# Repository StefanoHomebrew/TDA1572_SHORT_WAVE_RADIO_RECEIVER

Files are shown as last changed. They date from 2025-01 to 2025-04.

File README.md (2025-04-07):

Quello che vedete è molto sperimentale, in fase di sviluppo. Non posso dare assistenza tecnica e file gerber... Se trovate BUG e avete consigli utili, scrivetemi! Grazie!  Altrimenti che divertimento è!... A very experimental shortwave radio receiver with TDA1572, a vintage integrated circuit, external PLL & DDS Vfo and Arduino Mega 256. Gennaio 2025, AM-SSB-RTTY(in fase di sviluppo)---Aprile 2025--- Nuova release con AGC NUOVO! : RX_TDA1572_AGC_NEW_REV2.kicad_pcb

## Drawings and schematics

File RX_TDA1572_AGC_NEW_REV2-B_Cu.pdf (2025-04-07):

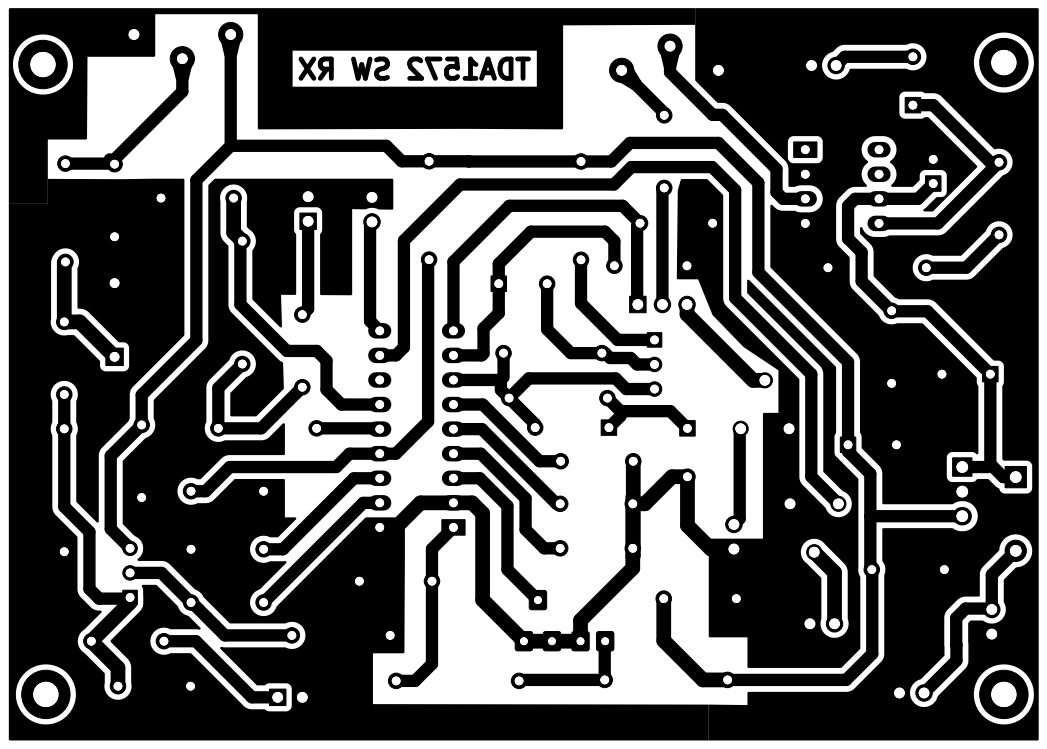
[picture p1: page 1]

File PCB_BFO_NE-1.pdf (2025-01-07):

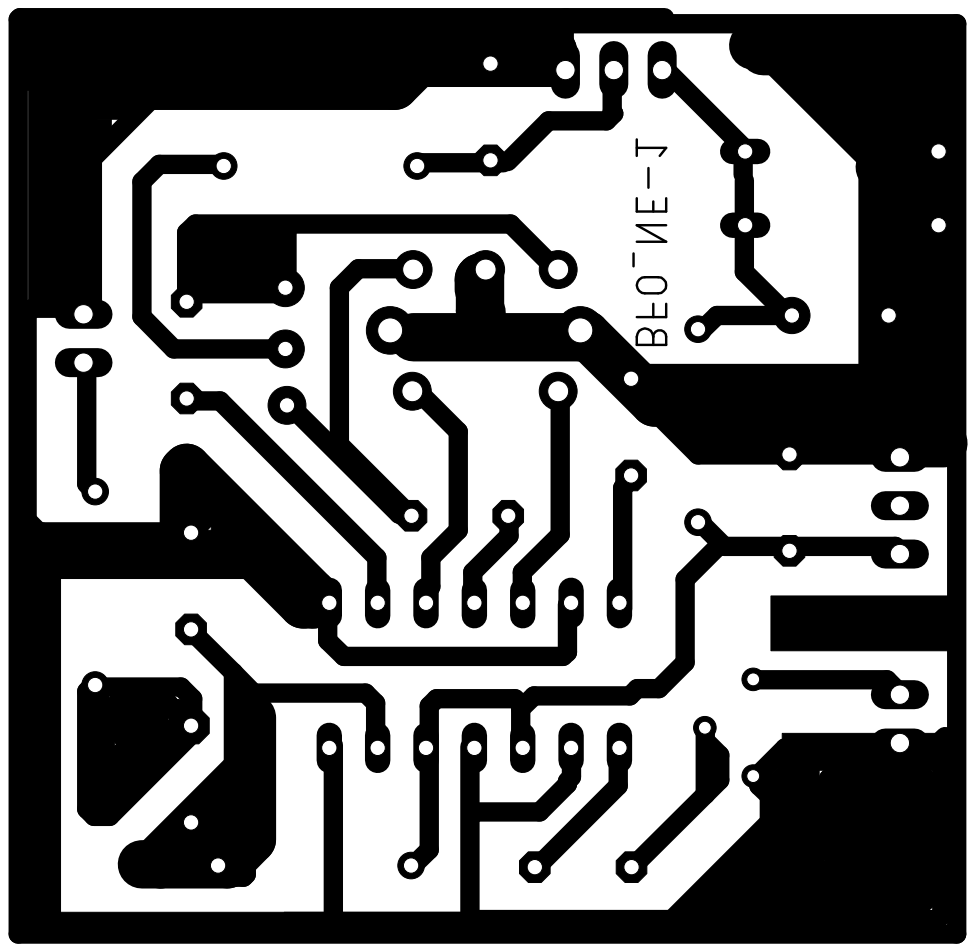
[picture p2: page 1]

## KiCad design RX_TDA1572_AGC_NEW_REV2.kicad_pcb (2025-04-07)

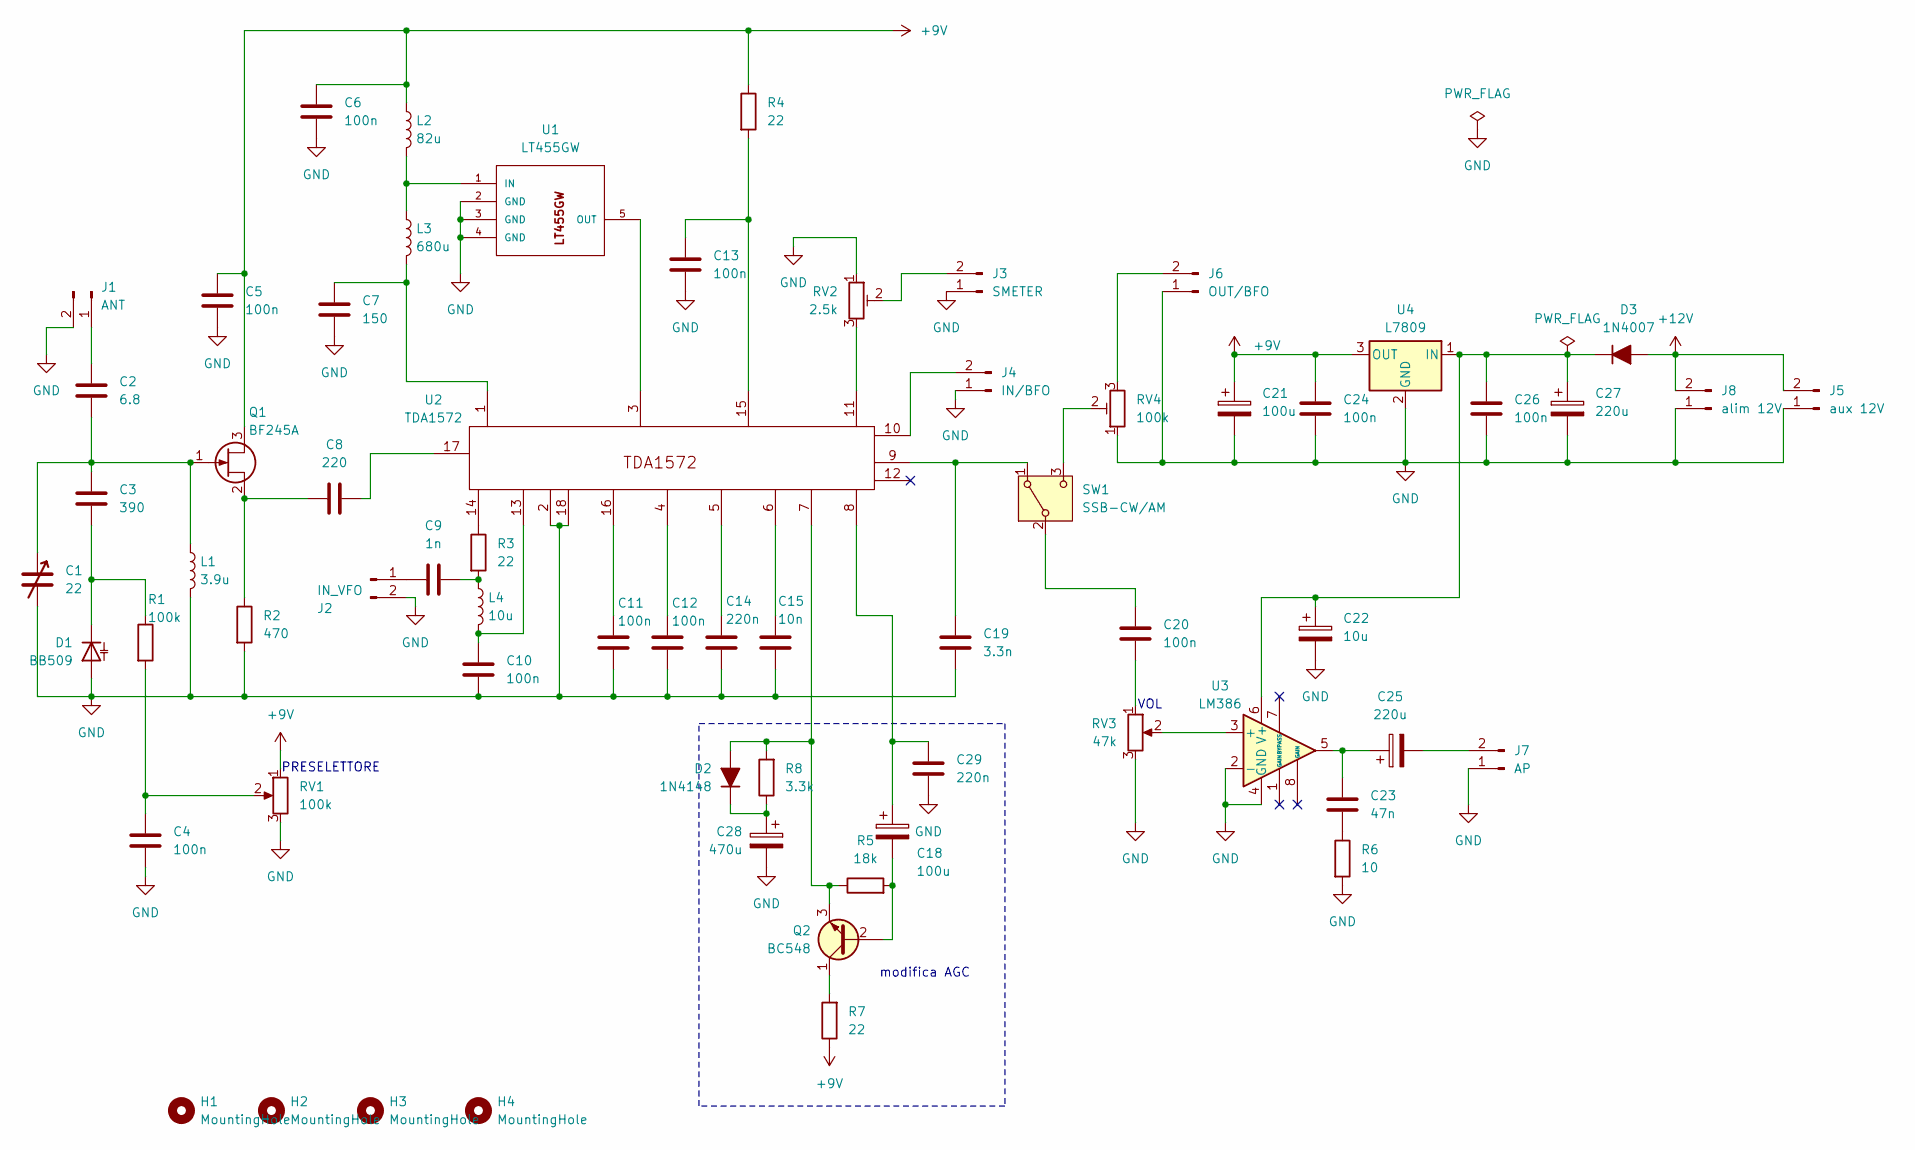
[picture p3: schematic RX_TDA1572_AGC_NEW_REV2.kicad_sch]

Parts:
C1: 22; C_Rect_L9.0mm_W3.4mm_P7.50mm_MKT
C2: 6.8; C_Rect_L9.0mm_W3.4mm_P7.50mm_MKT
C3: 390; C_Rect_L9.0mm_W3.4mm_P7.50mm_MKT
C4, C5, C6, C10, C11, C12, C13, C20, C24, C26: 100n; C_Rect_L9.0mm_W3.4mm_P7.50mm_MKT
C7: 150; C_Rect_L9.0mm_W3.4mm_P7.50mm_MKT
C8: 220; C_Rect_L9.0mm_W3.4mm_P7.50mm_MKT
C9: 1n; C_Rect_L9.0mm_W3.4mm_P7.50mm_MKT
C14, C29: 220n; C_Rect_L9.0mm_W3.4mm_P7.50mm_MKT
C15: 10n; C_Rect_L9.0mm_W3.4mm_P7.50mm_MKT
C18, C21: 100u; CP_Radial_D8.0mm_P5.00mm
C19: 3.3n; C_Rect_L9.0mm_W3.4mm_P7.50mm_MKT
C22: 10u; CP_Radial_D5.0mm_P2.50mm
C23: 47n; C_Rect_L9.0mm_W3.4mm_P7.50mm_MKT
C25, C27: 220u; CP_Radial_D8.0mm_P5.00mm
C28: 470u; CP_Radial_D8.0mm_P5.00mm
D1: BB509; D_A-405_P7.62mm_Horizontal
D2: 1N4148; D_DO-35_SOD27_P7.62mm_Horizontal
D3: 1N4007; D_DO-41_SOD81_P7.62mm_Horizontal
H1, H2, H3, H4: MountingHole; MountingHole_2.5mm_Pad
J1: ANT; PinHeader_1x02_P2.54mm_Vertical
J2: IN_VFO; PinHeader_1x02_P2.54mm_Vertical
J3: SMETER; PinHeader_1x02_P2.54mm_Vertical
J4: IN/BFO; PinHeader_1x02_P2.54mm_Vertical
J5: aux 12V; PinHeader_1x02_P2.54mm_Vertical
J6: OUT/BFO; PinHeader_1x02_P2.54mm_Vertical
J7: AP; PinHeader_1x02_P2.54mm_Vertical
J8: alim 12V; PinHeader_1x02_P2.54mm_Vertical
L1: 3.9u; L_Axial_L7.0mm_D3.3mm_P12.70mm_Horizontal_Fastron_MICC
L2: 82u; L_Axial_L7.0mm_D3.3mm_P12.70mm_Horizontal_Fastron_MICC
L3: 680u; L_Axial_L7.0mm_D3.3mm_P12.70mm_Horizontal_Fastron_MICC
L4: 10u; L_Axial_L7.0mm_D3.3mm_P12.70mm_Horizontal_Fastron_MICC
Q1: BF245A; TO-92_Inline_Wide
Q2: BC548; TO-92_Inline_Wide_CBE
R1: 100k; R_Axial_DIN0207_L6.3mm_D2.5mm_P10.16mm_Horizontal
R2: 470; R_Axial_DIN0207_L6.3mm_D2.5mm_P10.16mm_Horizontal
R3, R4, R7: 22; R_Axial_DIN0207_L6.3mm_D2.5mm_P10.16mm_Horizontal
R5: 18k; R_Axial_DIN0207_L6.3mm_D2.5mm_P10.16mm_Horizontal
R6: 10; R_Axial_DIN0207_L6.3mm_D2.5mm_P10.16mm_Horizontal
R8: 3.3k; R_Axial_DIN0207_L6.3mm_D2.5mm_P10.16mm_Horizontal
RV1: 100k; Potentiometer_Piher_PT-15-H01_Horizontal
RV2: 2.5k; Potentiometer_Runtron_RM-065_Vertical
RV3: 47k; Potentiometer_Piher_PT-15-H01_Horizontal
RV4: 100k; Potentiometer_Runtron_RM-065_Vertical
SW1: SSB-CW/AM; PinHeader_1x03_P2.54mm_Vertical
U1: LT455GW; CFW455IT
U2: TDA1572; DIP-18_W7.62mm_Socket_LongPads
U3: LM386; DIP-8_W7.62mm_Socket_LongPads
U4: L7809; TO-220-3_Vertical

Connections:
+9V: C5.1, C6.1, C21.1, C24.1, L2.1, Q1.3 (D), R4.1, R7.1, RV1.1, U4.3 (OUT)
+12V: D3.2 (A), J5.2, J8.2
GND: C1.2, C4.2, C5.2, C6.2, C7.2, C10.1, C11.1, C12.1, C13.2, C14.1, C15.1, C19.2, C21.2, C22.2, C24.2, C26.2, C27.2, C28.2, C29.2, D1.2 (A), J1.2, J2.2, J3.1, J4.1, J5.1, J6.1, J7.1, J8.1, L1.2, R2.2, R6.2, RV1.3, RV2.1, RV3.3, RV4.1, U1.2 (GND), U1.3 (GND), U1.4 (GND), U2.2, U2.18, U3.2 (-), U3.4 (GND), U4.2 (GND)
unnamed: C4.1, R1.2, RV1.2
unnamed: C7.1, L3.2, U2.1
unnamed: C8.2, U2.17
unnamed: C9.2, L4.1, R3.2
unnamed: C10.2, L4.2, U2.13
unnamed: C11.2, U2.16
unnamed: C12.2, U2.4
unnamed: C13.1, R4.2, U2.15
unnamed: C14.2, U2.5
unnamed: C15.2, U2.6
unnamed: C18.1, C29.1, U2.8
unnamed: C20.1, RV3.1
unnamed: C23.1, C25.1, U3.5
unnamed: C23.2, R6.1
unnamed: C3.2, D1.1 (K), R1.1
unnamed: D2.2 (A), Q2.3 (E), R5.1, R8.2, U2.7
unnamed: C28.1, D2.1 (K), R8.1
unnamed: C22.1, C26.1, C27.1, D3.1 (K), U3.6 (V+), U4.1 (IN)
unnamed: C2.1, J1.1
unnamed: C9.1, J2.1
unnamed: J3.2, RV2.2
unnamed: J4.2, U2.10
unnamed: J6.2, RV4.3
unnamed: C25.2, J7.2
unnamed: C1.1, C2.2, C3.1, L1.1, Q1.1 (G)
unnamed: C8.1, Q1.2 (S), R2.1
unnamed: C18.2, Q2.2 (B), R5.2
unnamed: Q2.1 (C), R7.2
unnamed: R3.1, U2.14
unnamed: RV2.3, U2.11
unnamed: C19.1, SW1.1 (A), U2.9
unnamed: C20.2, SW1.2 (B)
unnamed: RV4.2, SW1.3 (C)
unnamed: L2.2, L3.1, U1.1 (IN)
unnamed: U1.5 (OUT), U2.3
unnamed: RV3.2, U3.3 (+)

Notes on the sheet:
modifica AGC
PRESELETTORE
VOL

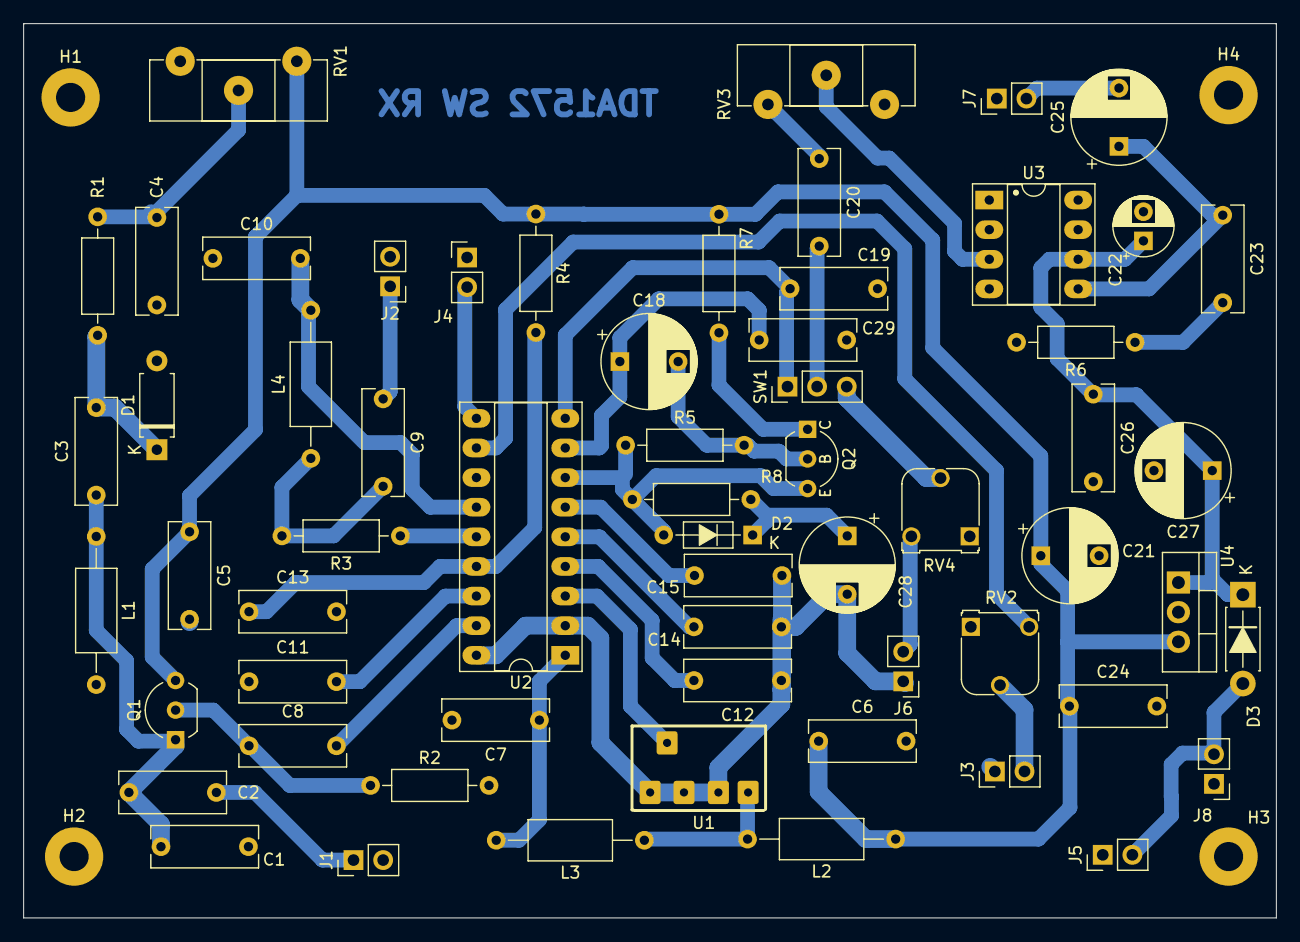
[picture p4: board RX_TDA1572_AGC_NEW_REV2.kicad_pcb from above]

Board: 2 copper layers, 107.4 x 76.7 mm, 65 parts (0 on the bottom side), 39 nets.

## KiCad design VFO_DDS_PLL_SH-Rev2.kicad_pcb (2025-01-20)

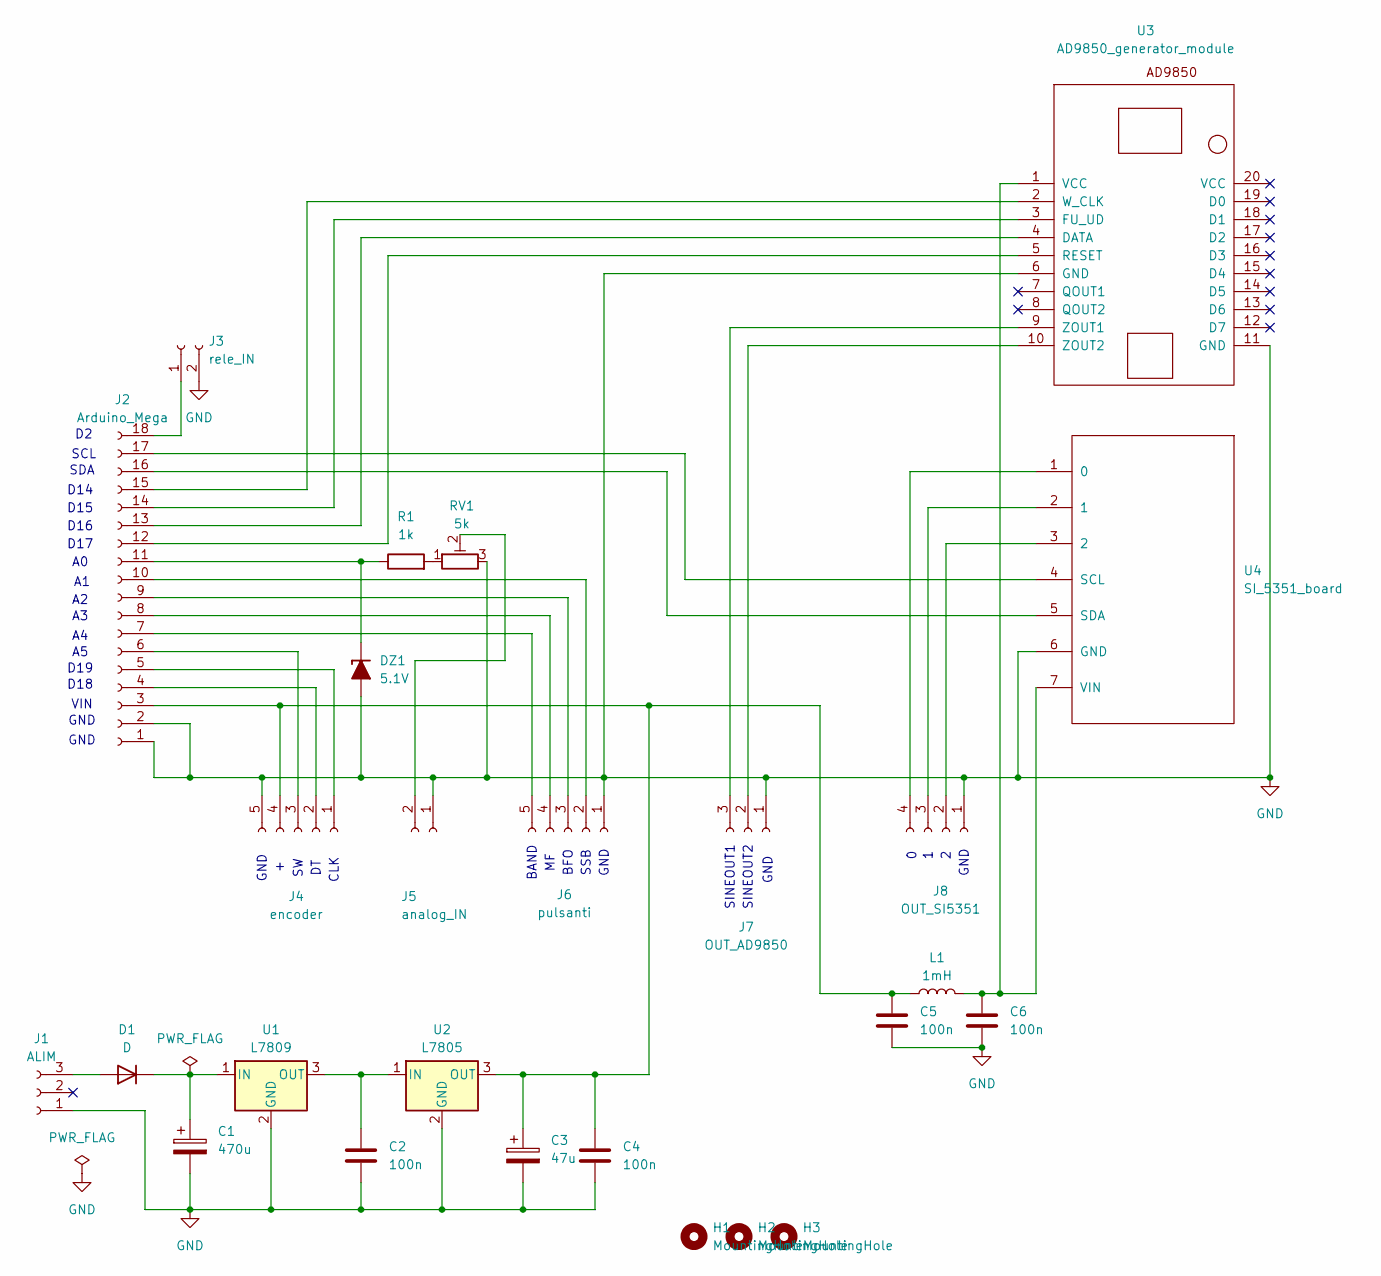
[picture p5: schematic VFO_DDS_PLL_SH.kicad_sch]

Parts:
C1: 470u; CP_Radial_D8.0mm_P3.50mm
C2, C4, C5, C6: 100n; C_Disc_D4.3mm_W1.9mm_P5.00mm
C3: 47u; CP_Radial_D8.0mm_P3.50mm
D1: D; D_DO-41_SOD81_P12.70mm_Horizontal
DZ1: 5.1V; D_DO-34_SOD68_P7.62mm_Horizontal_Zener
H1, H2, H3: MountingHole; MountingHole_2.2mm_M2_Pad
J1: ALIM; PinHeader_1x03_P2.54mm_Vertical
J2: Arduino_Mega; PinHeader_1x18_P2.54mm_Vertical
J3: rele_IN; PinHeader_1x02_P2.54mm_Vertical
J4: encoder; PinHeader_1x05_P2.54mm_Vertical
J5: analog_IN; PinHeader_1x02_P2.54mm_Vertical
J6: pulsanti; PinHeader_1x05_P2.54mm_Vertical
J7: OUT_AD9850; PinHeader_1x03_P2.54mm_Vertical
J8: OUT_SI5351; PinHeader_1x04_P2.54mm_Vertical
L1: 1mH; L_Axial_L5.3mm_D2.2mm_P10.16mm_Horizontal_Vishay_IM-1
R1: 1k; R_Axial_DIN0207_L6.3mm_D2.5mm_P10.16mm_Horizontal
RV1: 5k; Potentiometer_Runtron_RM-065_Vertical
U1: L7809; TO-220-3_Horizontal_TabDown
U2: L7805; TO-220-3_Horizontal_TabDown
U3: AD9850_generator_module; AD9850-MODUL
U4: SI_5351_board; SI5351_MODULE

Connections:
GND: C1.2, C2.2, C3.2, C4.2, C5.2, C6.2, DZ1.2 (A), J1.1, J2.1, J2.2, J3.2, J4.5, J5.1, J6.1, J7.1, J8.1, RV1.3, U1.2 (GND), U2.2 (GND), U3.6 (GND), U3.11 (GND), U4.6 (GND)
unnamed: D1.2 (A), J1.3
unnamed: C1.1, D1.1 (K), U1.1 (IN)
unnamed: DZ1.1 (K), J2.11, R1.1
unnamed: C3.1, C4.1, C5.1, J2.3, J4.4, L1.1, U2.3 (OUT)
unnamed: J2.4, J4.2
unnamed: J2.5, J4.1
unnamed: J2.6, J4.3
unnamed: J2.7, J6.5
unnamed: J2.8, J6.4
unnamed: J2.9, J6.3
unnamed: J2.10, J6.2
unnamed: J2.12, U3.5 (RESET)
unnamed: J2.13, U3.4 (DATA)
unnamed: J2.14, U3.3 (FU_UD)
unnamed: J2.15, U3.2 (W_CLK)
unnamed: J2.16, U4.5 (SDA)
unnamed: J2.17, U4.4 (SCL)
unnamed: J2.18, J3.1
unnamed: J5.2, RV1.2
unnamed: J7.2, U3.10 (ZOUT2)
unnamed: J7.3, U3.9 (ZOUT1)
unnamed: J8.2, U4.3 (2)
unnamed: J8.3, U4.2 (1)
unnamed: J8.4, U4.1 (0)
unnamed: R1.2, RV1.1
unnamed: C2.1, U1.3 (OUT), U2.1 (IN)
unnamed: C6.1, L1.2, U3.1 (VCC), U4.7 (VIN)

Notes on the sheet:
BAND
SINEOUT2
SDA
GND
D18
SCL
VIN
CLK
SINEOUT1
SSB
BFO
D17
D15
D14
D16
D19

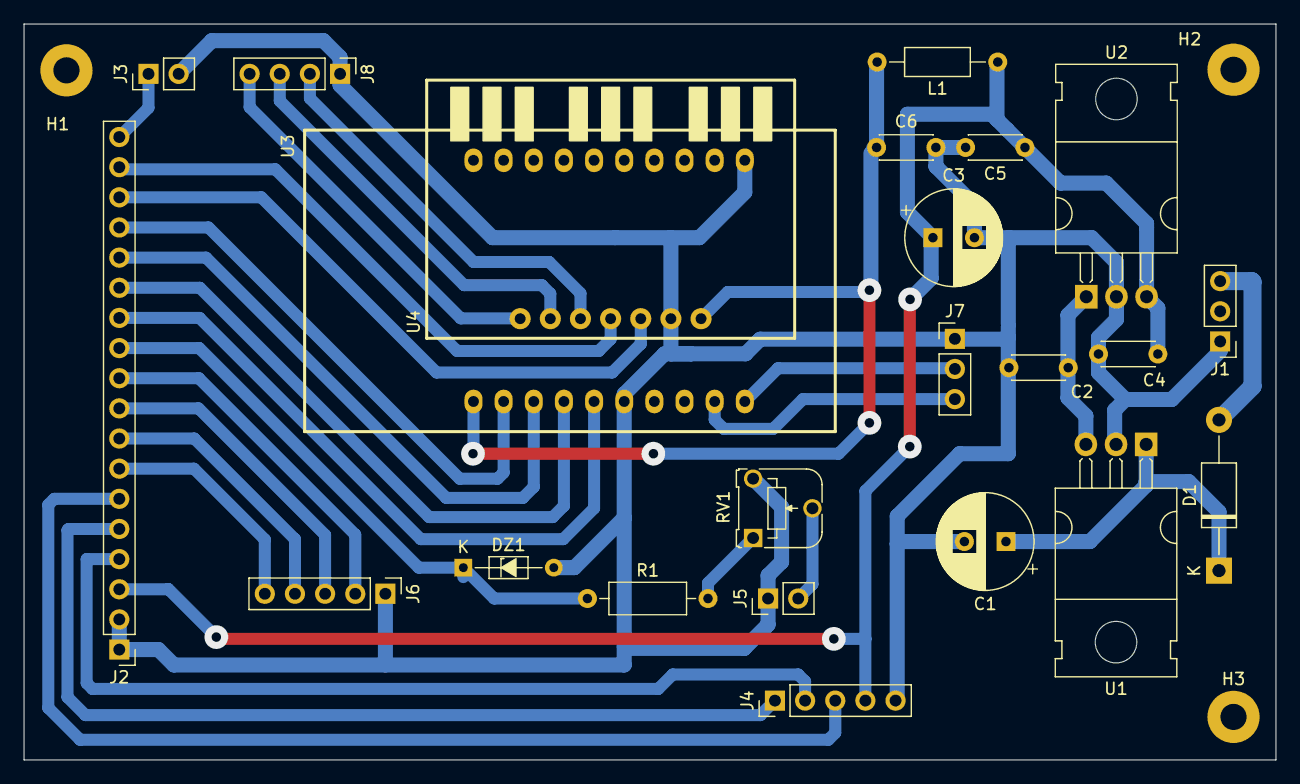
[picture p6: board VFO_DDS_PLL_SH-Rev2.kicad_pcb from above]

Board: 2 copper layers, 105.5 x 62.0 mm, 26 parts (0 on the bottom side), 28 nets.

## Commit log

2025-01-06 Add files via upload
    File .HEX per Arduino Mega 2560 Ricevitore per Onde Corte con TDA1572 - AM -SSB - RTTY (in fase di sviluppo)
2025-01-20 ERRATA CORRIGE----Rev.2
    [VFO_DDS_PLL_SH-Rev2.kicad_pcb]
2025-04-07 Nuova Versione AGC NEW
    [RX_TDA1572_AGC_NEW_REV2.kicad_pcb, RX_TDA1572_AGC_NEW_REV2.kicad_sch]
2025-05-10 SCHEMA ELETTRICO VFO DDS
    [VFO_DDS_PLL_SH.kicad_sch]
